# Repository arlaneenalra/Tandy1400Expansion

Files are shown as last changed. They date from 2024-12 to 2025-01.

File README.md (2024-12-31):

Tandy 1400 FD/HD Expansion Card
===============================

An experimental expansion card for the Tandy 1400 HD/FD series laptops. It might work on an LT but I don't have one for testing.

# "'nosys.specs': No such file or directory" error
See: https://github.com/raspberrypi/pico-feedback/issues/355

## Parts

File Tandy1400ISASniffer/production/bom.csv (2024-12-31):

Designator | Footprint | Quantity | Value | LCSC Part #
C1, C10, C11, C12, C13, C14, C2, C3, C4, C5, C6, C7, C8, C9 | 0603 | 14 | 0.1uF | C6119861
D1 | D_SOD-123 | 1 | 1N5817W | C5185908
J2 | PinHeader_1x07_P2.54mm_Vertical | 1 | EXTRA_GPIO
R1, R2, R3, R4, R5, R6, R7 | 0402 | 7 | 10k | C25744
U1, U3, U4 | TSSOP-48_6.1x12.5mm_P0.5mm | 3 | 74ALVC164245 | C2652966
U2 | RPi_Pico_SMD_TH | 1 | Pico
U5 | TSSOP-20_4.4x6.5mm_P0.65mm | 1 | 74HCT373 | C240801

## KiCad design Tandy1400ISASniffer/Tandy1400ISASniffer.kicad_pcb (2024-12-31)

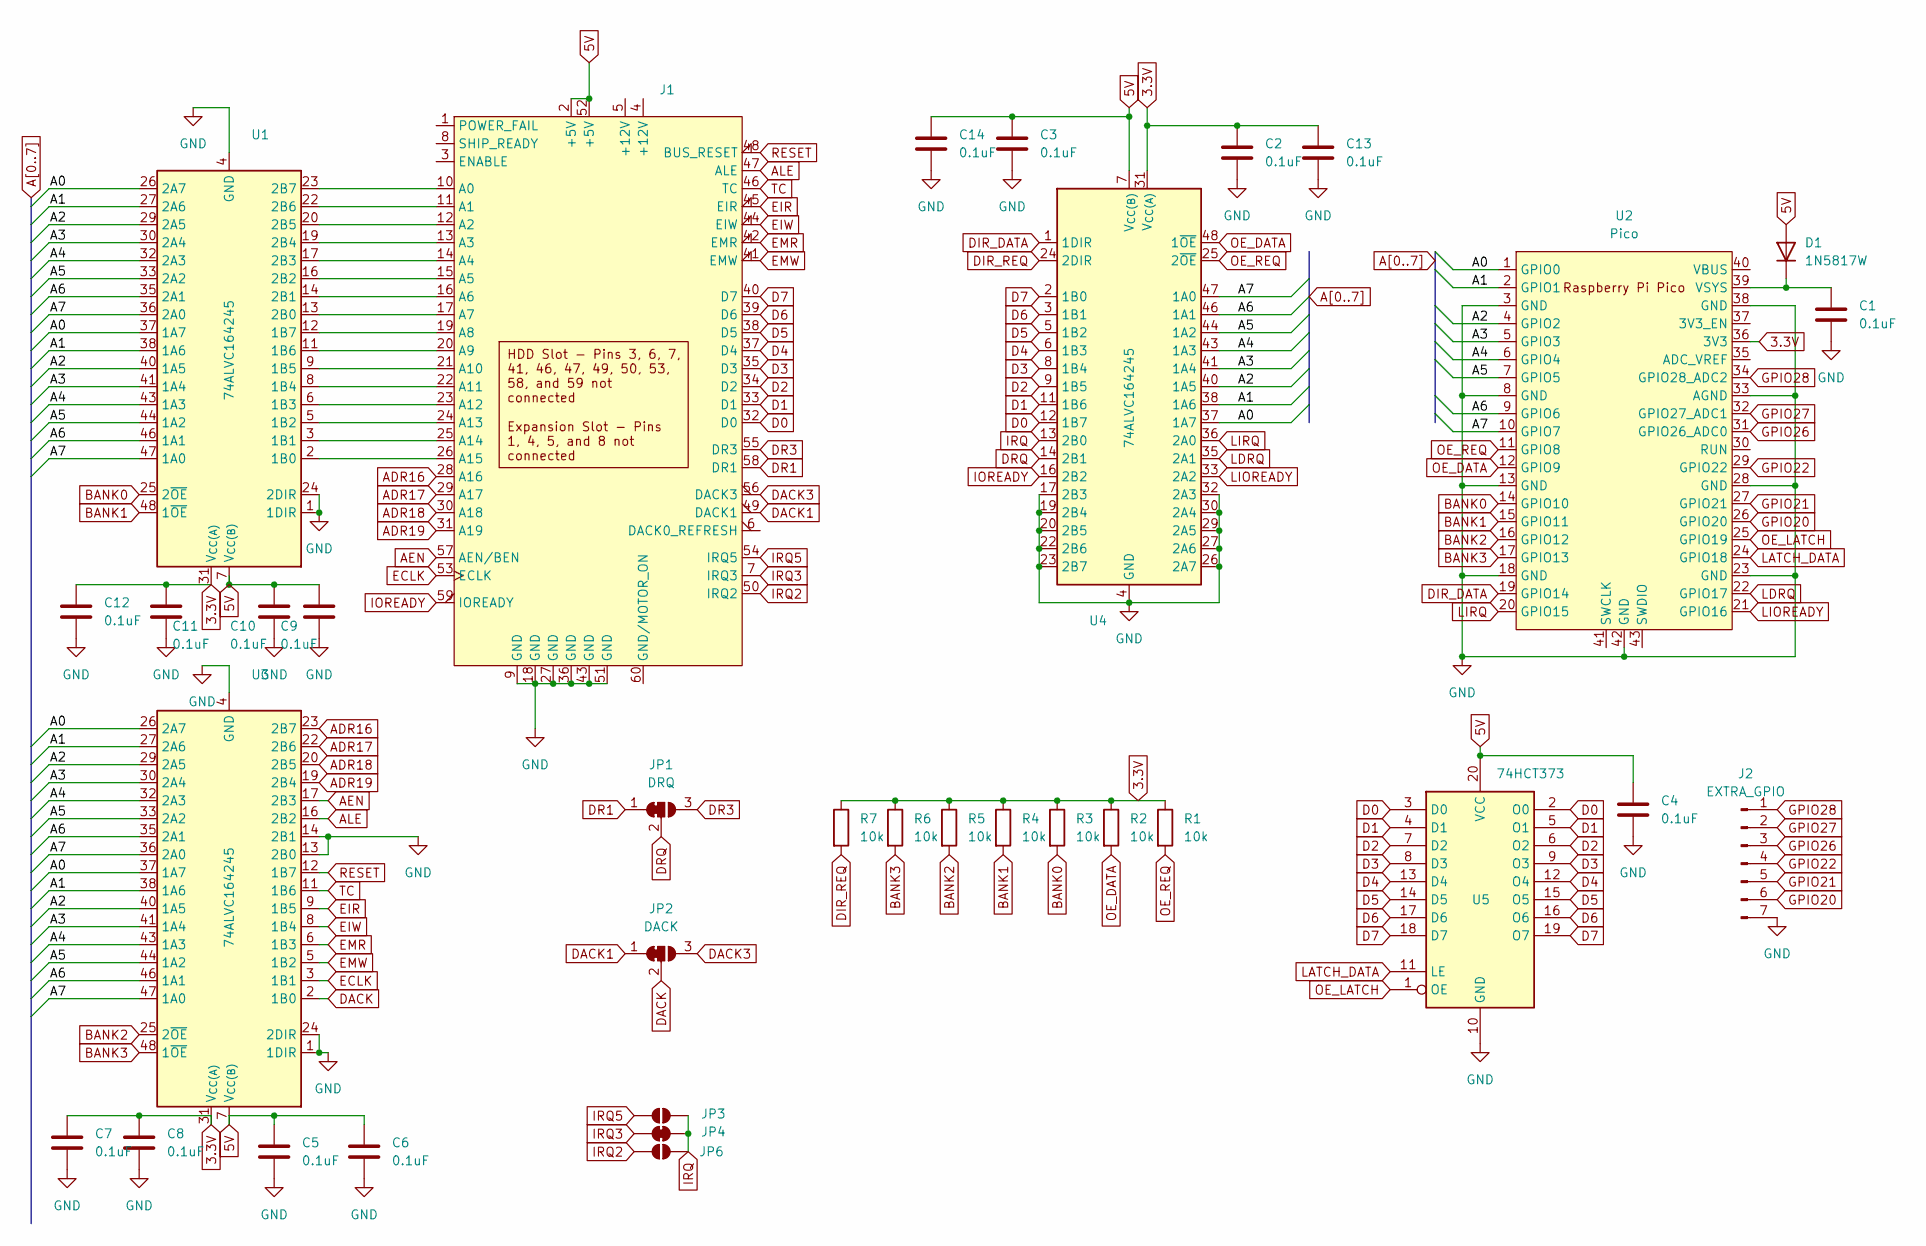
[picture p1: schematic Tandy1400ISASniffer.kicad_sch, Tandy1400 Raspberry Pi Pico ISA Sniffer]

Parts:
C1, C2, C3, C4, C5, C6, C7, C8, C9, C10, C11, C12, C13, C14: 0.1uF; C_0603_1608Metric; LCSC C6119861
D1: 1N5817W; D_SOD-123; LCSC C5185908
J1: TANDY_1400_EXPANSION_1
J2: EXTRA_GPIO; PinHeader_1x07_P2.54mm_Vertical
JP1: DRQ; SolderJumper-3_P1.3mm_Bridged2Bar12_RoundedPad1.0x1.5mm_Num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
JP2: DACK; SolderJumper-3_P1.3mm_Bridged2Bar12_RoundedPad1.0x1.5mm_Num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
JP3: IRQ5; SolderJumper-2_P1.3mm_Open_RoundedPad1.0x1.5mm
JP4: IRQ3; SolderJumper-2_P1.3mm_Bridged_RoundedPad1.0x1.5mm
JP6: IRQ2; SolderJumper-2_P1.3mm_Open_RoundedPad1.0x1.5mm
R1, R2, R3, R4, R5, R6, R7: 10k; R_0402_1005Metric; LCSC C25744
U1, U3, U4: 74ALVC164245; TSSOP-48_6.1x12.5mm_P0.5mm; LCSC C2652966
U2: Pico; RPi_Pico_SMD_TH
U5: 74HCT373; TSSOP-20_4.4x6.5mm_P0.65mm; LCSC C240801

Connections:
3.3V: C2.1, C7.1, C8.1, C11.1, C12.1, C13.1, R1.1, R2.1, R3.1, R4.1, R5.1, R6.1, R7.1, U1.31 (V_{CC(A)}), U1.42 (V_{CC(A)}), U2.36 (3V3), U3.31 (V_{CC(A)}), U3.42 (V_{CC(A)}), U4.31 (V_{CC(A)}), U4.42 (V_{CC(A)})
5V: C3.1, C4.1, C5.1, C6.1, C9.1, C10.1, C14.1, D1.2 (A), J1.2 (+5V), J1.52 (+5V), U1.7 (V_{CC(B)}), U1.18 (V_{CC(B)}), U3.7 (V_{CC(B)}), U3.18 (V_{CC(B)}), U4.7 (V_{CC(B)}), U4.18 (V_{CC(B)}), U5.20 (VCC)
A0: U1.26 (2A7), U1.37 (1A7), U2.1 (GPIO0), U3.26 (2A7), U3.37 (1A7), U4.37 (1A7)
A1: U1.27 (2A6), U1.38 (1A6), U2.2 (GPIO1), U3.27 (2A6), U3.38 (1A6), U4.38 (1A6)
A2: U1.29 (2A5), U1.40 (1A5), U2.4 (GPIO2), U3.29 (2A5), U3.40 (1A5), U4.40 (1A5)
A3: U1.30 (2A4), U1.41 (1A4), U2.5 (GPIO3), U3.30 (2A4), U3.41 (1A4), U4.41 (1A4)
A4: U1.32 (2A3), U1.43 (1A3), U2.6 (GPIO4), U3.32 (2A3), U3.43 (1A3), U4.43 (1A3)
A5: U1.33 (2A2), U1.44 (1A2), U2.7 (GPIO5), U3.33 (2A2), U3.44 (1A2), U4.44 (1A2)
A6: U1.35 (2A1), U1.46 (1A1), U2.9 (GPIO6), U3.35 (2A1), U3.46 (1A1), U4.46 (1A1)
A7: U1.36 (2A0), U1.47 (1A0), U2.10 (GPIO7), U3.36 (2A0), U3.47 (1A0), U4.47 (1A0)
ADR16: J1.28 (A16), U3.23 (2B7)
ADR17: J1.29 (A17), U3.22 (2B6)
ADR18: J1.30 (A18), U3.20 (2B5)
ADR19: J1.31 (A19), U3.19 (2B4)
AEN: J1.57 (AEN/BEN), U3.17 (2B3)
ALE: J1.47 (ALE), U3.16 (2B2)
BANK0: R3.2, U1.25 (2~OE), U2.14 (GPIO10)
BANK1: R4.2, U1.48 (1~OE), U2.15 (GPIO11)
BANK2: R5.2, U2.16 (GPIO12), U3.25 (2~OE)
BANK3: R6.2, U2.17 (GPIO13), U3.48 (1~OE)
D0: J1.32 (D0), U4.12 (1B7), U5.2 (O0), U5.3 (D0)
D1: J1.33 (D1), U4.11 (1B6), U5.4 (D1), U5.5 (O1)
D2: J1.34 (D2), U4.9 (1B5), U5.6 (O2), U5.7 (D2)
D3: J1.35 (D3), U4.8 (1B4), U5.8 (D3), U5.9 (O3)
D4: J1.37 (D4), U4.6 (1B3), U5.12 (O4), U5.13 (D4)
D5: J1.38 (D5), U4.5 (1B2), U5.14 (D5), U5.15 (O5)
D6: J1.39 (D6), U4.3 (1B1), U5.16 (O6), U5.17 (D6)
D7: J1.40 (D7), U4.2 (1B0), U5.18 (D7), U5.19 (O7)
DACK: JP2.2 (C), U3.2 (1B0)
DACK1: J1.49 (DACK1), JP2.1 (A)
DACK3: J1.56 (DACK3), JP2.3 (B)
DIR_DATA: U2.19 (GPIO14), U4.1 (1DIR)
DIR_REQ: R7.2, U4.24 (2DIR)
DR1: J1.58 (DR1), JP1.1 (A)
DR3: J1.55 (DR3), JP1.3 (B)
DRQ: JP1.2 (C), U4.14 (2B1)
ECLK: J1.53 (ECLK), U3.3 (1B1)
EIR: J1.45 (EIR), U3.9 (1B5)
EIW: J1.44 (EIW), U3.8 (1B4)
EMR: J1.42 (EMR), U3.6 (1B3)
EMW: J1.41 (EMW), U3.5 (1B2)
GND: C1.2, C2.2, C3.2, C4.2, C5.2, C6.2, C7.2, C8.2, C9.2, C10.2, C11.2, C12.2, C13.2, C14.2, J1.9 (GND), J1.18 (GND), J1.27 (GND), J1.36 (GND), J1.43 (GND), J1.51 (GND), J2.7, U1.1 (1DIR), U1.4 (GND), U1.10 (GND), U1.15 (GND), U1.21 (GND), U1.24 (2DIR), U1.28 (GND), U1.34 (GND), U1.39 (GND), U1.45 (GND), U2.3 (GND), U2.8 (GND), U2.13 (GND), U2.18 (GND), U2.23 (GND), U2.28 (GND), U2.33 (AGND), U2.38 (GND), U2.42 (GND), U3.1 (1DIR), U3.4 (GND), U3.10 (GND), U3.13 (2B0), U3.14 (2B1), U3.15 (GND), U3.21 (GND), U3.24 (2DIR), U3.28 (GND), U3.34 (GND), U3.39 (GND), U3.45 (GND), U4.4 (GND), U4.10 (GND), U4.15 (GND), U4.17 (2B3), U4.19 (2B4), U4.20 (2B5), U4.21 (GND), U4.22 (2B6), U4.23 (2B7), U4.26 (2A7), U4.27 (2A6), U4.28 (GND), U4.29 (2A5), U4.30 (2A4), U4.32 (2A3), U4.34 (GND), U4.39 (GND), U4.45 (GND), U5.10 (GND)
GPIO20: J2.6, U2.26 (GPIO20)
GPIO21: J2.5, U2.27 (GPIO21)
GPIO22: J2.4, U2.29 (GPIO22)
GPIO26: J2.3, U2.31 (GPIO26_ADC0)
GPIO27: J2.2, U2.32 (GPIO27_ADC1)
GPIO28: J2.1, U2.34 (GPIO28_ADC2)
IOREADY: J1.59 (IOREADY), U4.16 (2B2)
IRQ: JP3.2 (B), JP4.2 (B), JP6.2 (B), U4.13 (2B0)
IRQ2: J1.50 (IRQ2), JP6.1 (A)
IRQ3: J1.7 (IRQ3), JP4.1 (A)
IRQ5: J1.54 (IRQ5), JP3.1 (A)
LATCH_DATA: U2.24 (GPIO18), U5.11 (LE)
LDRQ: U2.22 (GPIO17), U4.35 (2A1)
LIOREADY: U2.21 (GPIO16), U4.33 (2A2)
LIRQ: U2.20 (GPIO15), U4.36 (2A0)
unnamed: C1.1, D1.1 (K), U2.39 (VSYS)
unnamed: J1.10 (A0), U1.23 (2B7)
unnamed: J1.11 (A1), U1.22 (2B6)
unnamed: J1.12 (A2), U1.20 (2B5)
unnamed: J1.13 (A3), U1.19 (2B4)
unnamed: J1.14 (A4), U1.17 (2B3)
unnamed: J1.15 (A5), U1.16 (2B2)
unnamed: J1.16 (A6), U1.14 (2B1)
unnamed: J1.17 (A7), U1.13 (2B0)
unnamed: J1.19 (A8), U1.12 (1B7)
unnamed: J1.20 (A9), U1.11 (1B6)
unnamed: J1.21 (A10), U1.9 (1B5)
unnamed: J1.22 (A11), U1.8 (1B4)
unnamed: J1.23 (A12), U1.6 (1B3)
unnamed: J1.24 (A13), U1.5 (1B2)
unnamed: J1.25 (A14), U1.3 (1B1)
unnamed: J1.26 (A15), U1.2 (1B0)
OE_DATA: R2.2, U2.12 (GPIO9), U4.48 (1~OE)
OE_LATCH: U2.25 (GPIO19), U5.1 (OE)
OE_REQ: R1.2, U2.11 (GPIO8), U4.25 (2~OE)
RESET: J1.48 (BUS_RESET), U3.12 (1B7)
TC: J1.46 (TC), U3.11 (1B6)

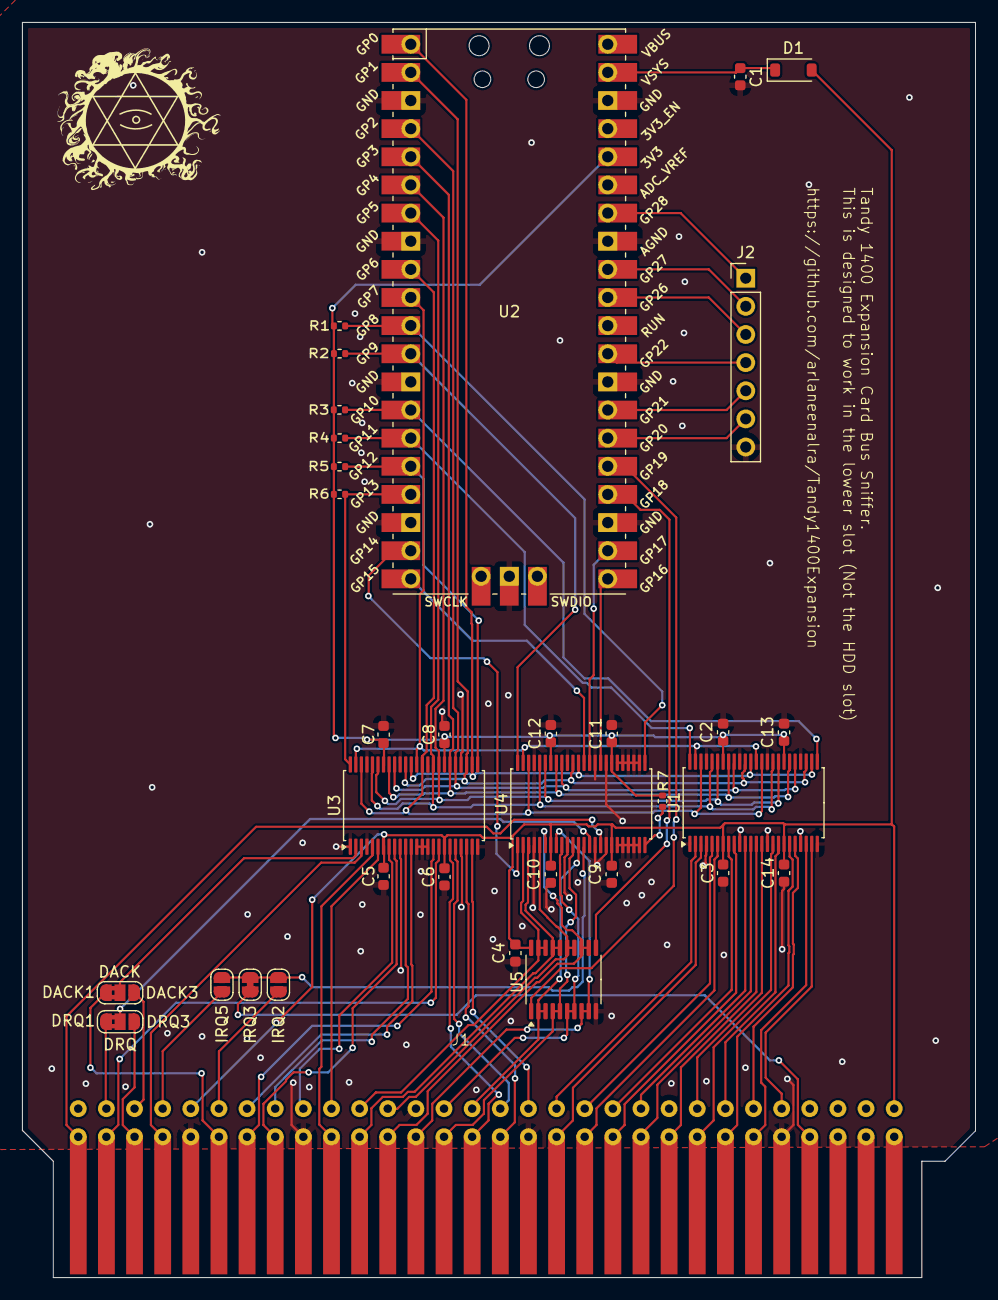
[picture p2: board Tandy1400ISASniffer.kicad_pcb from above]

Board: 2 copper layers, 86.0 x 113.3 mm, 34 parts (0 on the bottom side), 79 nets.

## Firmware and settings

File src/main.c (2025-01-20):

#include <stdio.h>
#include "pico/stdlib.h"
#include "pico/multicore.h"
#include "pico/util/queue.h"
#include "hardware/gpio.h"
#include "hardware/clocks.h"

#include "isa/isa.h"

typedef struct frame_type {
  uint8_t frame; 
  uint32_t dropped;
  isa_bus_state_t isa; 
} frame_t;

#define BUS_FRAMES 100

uint8_t bus_frame = 0;

queue_t bus_queue;

void __not_in_flash_func(poll_bus)() {
  frame_t frame;

  while(true) {
    frame.frame = bus_frame;

//    isa_wait_for_addr(isa);
//    isa_read_operation(isa);
      isa_read_bus(&frame.isa);
 
    // Did we drop a frame?
    if (queue_try_add(&bus_queue, &frame)) {
      bus_frame = (bus_frame + 1) % BUS_FRAMES;
      frame.dropped = 0;
    } else {
      frame.dropped++;
    }
  }
}

int main() {
  uint8_t count = 0;
  frame_t frame;
  isa_bus_state_t *isa;

  set_sys_clock_khz(250000, true);

  // Setup LED
  gpio_init(PICO_DEFAULT_LED_PIN);
  gpio_set_dir(PICO_DEFAULT_LED_PIN, GPIO_OUT);

  stdio_init_all();
  init_isa_bus();

  // Setup the bus queue 
  queue_init(&bus_queue, sizeof(frame_t), BUS_FRAMES);

  // Start bus poller
  multicore_launch_core1(poll_bus);

  gpio_put(PICO_DEFAULT_LED_PIN, true);

  while (true) {
    if (queue_try_remove(&bus_queue, &frame)) {
      isa = &frame.isa;
      if ((isa->addr < 0xBC000u) && (isa->addr > 0xB8000u)) {
//      if (isa->addr > 0xFFF00u) {      
        printf("OP: %i -> %i\n",
          frame.frame, frame.dropped);
        printf("0x%05X:0b%08b 0x%02X\n",
          isa->addr,
          isa->operation & BUS_OP_COMMAND,
          isa->data);
      }
    }
    tight_loop_contents();
  }
}

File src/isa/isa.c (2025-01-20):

#include <strings.h>

#include "isa.h"

#define ISA_PIO pio0
#define ISA_ADDR_SM 0

/**
 * ISA reference timings https://gist.github.com/PhirePhly/2209518
 */

void init_isa_bus() {
  // Disable pulls
  uint32_t gpio_mask = DATA_FUNCTION_MASK;
  for (int i = 0; i < 32; i ++ ) {
    // We're assuming a continuous block of gpios 
    if (!(gpio_mask & 1u )) {
      break;
    }
      
     gpio_set_pulls(i, false, false);
     //gpio_set_input_hysteresis_enabled(i, false);
     gpio_set_slew_rate(i, GPIO_SLEW_RATE_FAST); 

     gpio_mask >>= 1;
  }

  // Set everything to inputs for now.
  gpio_set_dir_in_masked(DATA_FUNCTION_MASK);
  gpio_put_masked(CONTROL_MASK, OE_MASK | SET_BIT(OE_LATCH));
  gpio_set_function_masked(CONTROL_MASK, GPIO_FUNC_SIO);

  // Control lines are always outputs
  gpio_set_dir_out_masked(CONTROL_MASK);

  gpio_put(DIR_DATA, false);

  // Setup the isa address reader pio.
  uint isa_addr_offset = pio_add_program(ISA_PIO, &isa_addr_program);
  pio_sm_claim(ISA_PIO, ISA_ADDR_SM);
  isa_addr_pio_init(ISA_PIO, ISA_ADDR_SM, isa_addr_offset);
}

/**
 * Bank output enables are all active low.
 * 
 */
void __not_in_flash_func(__isa_set_bank)(uint32_t bank) {
  gpio_put_masked(OE_MASK, ~bank);

  pico_default_asm_volatile("nop");
  pico_default_asm_volatile("nop");
  pico_default_asm_volatile("nop");
  pico_default_asm_volatile("nop");
}

/**
 * Reads an address from the bus.
 */
void __not_in_flash_func(isa_read_operation)(isa_bus_state_t *bus) {
  uint32_t buf, buf1, buf2;

  // Pull the 20bit address
  isa_set_bank(BANK_0);
  buf = gpio_get_all();

  isa_set_bank(BANK_1);
  buf1 = gpio_get_all();

  isa_set_bank(BANK_2);
  buf2 = gpio_get_all();

  bus->addr = (buf & DATA_MASK) |
    ((buf1 & DATA_MASK) << 8) |
    ((buf1 & 0x0F) << 16);
//  bus->addr = buf & DATA_MASK;

  // If we're in a write operation, data should be valid at this point.
  gpio_put(DIR_DATA, false);
  isa_set_bank(OE_DATA);
  bus->data = gpio_get_all() & DATA_MASK;
}


/**
 * Waits for ALE to go high then low.
 * Addresses are considered valid when ALE goes low.
 */
void __not_in_flash_func(isa_wait_for_addr)(isa_bus_state_t *bus) {
  uint32_t bank2, bank1, bank0;

  isa_set_bank(BANK_2);
  // Wait for rising edge
  do {
    tight_loop_contents();
    bank2 = gpio_get_all();
  } while ((bank2 & BUS_ALE) != BUS_ALE);

  // Wait for falling edge
  do {
    tight_loop_contents();
    bank2 = gpio_get_all();
  } while ((bank2 & BUS_ALE) != 0);

  // Pull the 20bit address
  isa_set_bank(BANK_0);
  bank0 = gpio_get_all();

  isa_set_bank(BANK_1);
  bank1 = gpio_get_all();

  bus->addr = (bank0 & DATA_MASK) |
    ((bank1 & DATA_MASK) << 8) |
    ((bank2 & 0x0F) << 16);

  isa_set_bank(BANK_3);
  bus->operation = gpio_get_all() & DATA_MASK;

  gpio_put(DIR_DATA, false);
  isa_set_bank(OE_DATA);
  bus->data = gpio_get_all() & DATA_MASK;
}

/**
 * Use PIO to read an address and data byte
 */
void __not_in_flash_func(isa_read_bus)(isa_bus_state_t * bus) {
  uint32_t raw_bus = pio_sm_get_blocking(ISA_PIO, ISA_ADDR_SM);

  bus->addr = (raw_bus &  0x0FFFFF00) >> 8; // mask off address
  bus->operation = (raw_bus & 0x000000FF); // Mask of operation
  bus->data = 0x00; // not reading data right now. 
}
